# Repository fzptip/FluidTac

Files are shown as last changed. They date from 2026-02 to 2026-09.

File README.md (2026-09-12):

# FluidTac

## A Vision-Based Arrayed Artificial Lateral Line Sensor for Underwater Ego-Motion Estimation

<p align="center">
  
  
  
</p>

**Zhipeng Fei\*, Yicheng Lin\*, Hengpeng Xie, Cong Li, and Bin Han**  

Published in **IEEE Robotics and Automation Letters (RA-L), 2026**.

[[Paper]](https://doi.org/10.1109/LRA.2026.3732929) [[Fabrication Guide]](./FluidTac%20Quick%20Start%20Guide.pdf) [[Code]](./Code) [[Model]](./Model)

## Overview

Reliable ego-motion estimation is essential for autonomous underwater vehicles (AUVs), but conventional sensing methods can degrade in shallow, turbid, and unstructured environments. Doppler velocity logs may lose bottom lock, while vision-based approaches depend on sufficient visibility and image features.

**FluidTac** is a compact, vision-based arrayed artificial lateral line sensor designed to provide robust velocity observations without relying on acoustic bottom tracking or external visual features. Inspired by the lateral line system of fish, FluidTac uses an array of passive propellers to convert local water-flow disturbances into visually observable rotations. A built-in camera tracks the rotational motion of the propellers, and the resulting signals are combined with inertial measurements for underwater ego-motion estimation.

## Method

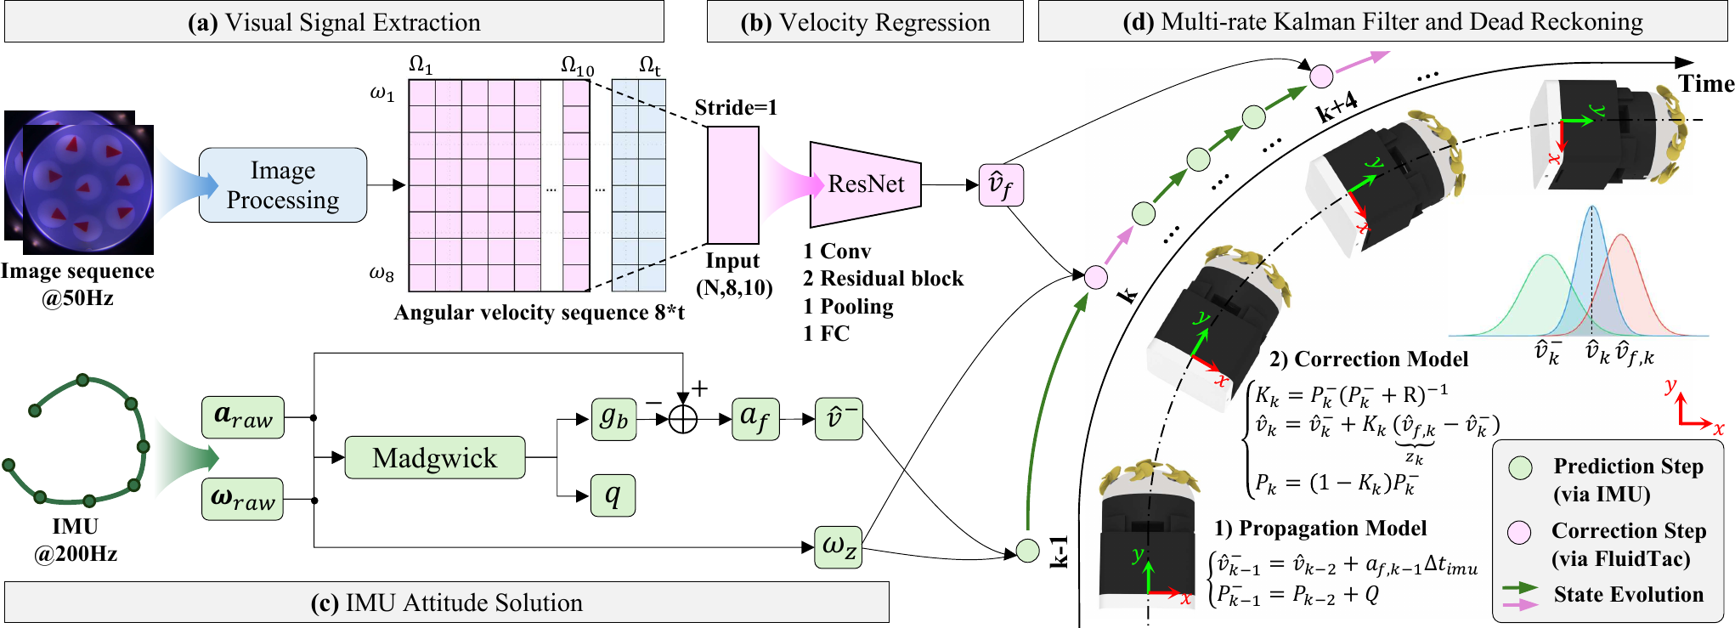
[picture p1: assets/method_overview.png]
Overview of the FluidTac ego-motion estimation framework


The proposed framework consists of four main stages:

1. **Visual signal extraction.** A camera captures the passive propeller array at 50 Hz. Image processing and marker tracking recover the angular velocity of each propeller.
2. **Velocity regression.** A sliding window containing the angular velocities of the eight sensing units is processed by a lightweight 1D ResNet to estimate the vehicle's forward velocity.
3. **IMU attitude estimation.** Raw 200 Hz accelerometer and gyroscope measurements are processed using a Madgwick filter to estimate attitude and gravity-compensated forward acceleration.
4. **Multi-rate sensor fusion.** A Kalman filter propagates the state using high-frequency inertial measurements and corrects the velocity whenever a new FluidTac observation becomes available. The fused velocity and yaw rate are then used for planar dead reckoning.

## Sensor Design

FluidTac employs eight passive propeller units arranged in an omnidirectional circular array. Water flow drives the propellers, while red asymmetric markers rigidly connected to their shafts provide visually trackable angular information. A single wide-angle camera observes all sensing units simultaneously, and an annular LED array provides stable internal illumination.

| Parameter | Value |
| --- | ---: |
| Sensor dimensions | 50 × 50 × 75 mm |
| Total mass | 76.17 g |
| Number of propeller units | 8 |
| Sensing diameter | 25 mm |
| Sampling rate | 50 Hz |
| Velocity range | 0.05-0.50 m/s |
| Front flow-angle range | ±90° |
| Velocity relative error | 3.49% |
| Flow-direction error | 1.71° |
| Signal-to-noise ratio | 5.35-10.04 dB |

## Experiments

FluidTac was evaluated through controlled experiments and real-world field trials:

- **Flow-direction sensing:** the sensor was rotated from -90° to 90° in a controlled current.
- **Velocity sensing:** towing experiments evaluated velocity estimation from 0.1 m/s to 0.5 m/s.
- **Ego-motion estimation:** rectangular and circular trajectories were tested in a motion-capture-equipped water tank.
- **Field validation:** FluidTac was integrated into an AUV and tested in a shallow, highly turbid natural lake.

In the controlled ego-motion experiments, FluidTac achieved the following performance:

| Metric | Result |
| --- | ---: |
| Velocity MAE | 7.99 mm/s |
| Velocity relative error | 3.49% |
| Position MAE | 5.48 cm |
| Position RMSE | 6.57 cm |
| Relative position error | 6.85% of traveled distance |

The lake experiments further demonstrated that FluidTac can constrain inertial drift and maintain reliable trajectory estimation in visually degraded, acoustically constrained environments.

## Repository Contents

```text
FluidTac/
├── Code/                         # Source code
├── Model/                        # FluidTac mechanical model
├── FluidTac Quick Start Guide.pdf
└── README.md
```

- [`Code/`](./Code): source code associated with FluidTac.
- [`Model/`](./Model): mechanical model files for the sensor.
- [`FluidTac Quick Start Guide.pdf`](./FluidTac%20Quick%20Start%20Guide.pdf): fabrication and assembly guide.

## Citation

If you find FluidTac useful in your research, please cite our paper:

```bibtex
@article{fei2026fluidtac,
  author  = {Zhipeng Fei and Yicheng Lin and Hengpeng Xie and Cong Li and Bin Han},
  title   = {{FluidTac}: A Vision-Based Arrayed Artificial Lateral Line Sensor for Underwater Ego-Motion Estimation},
  journal = {IEEE Robotics and Automation Letters},
  year    = {2026},
  pages   = {1--8},
  doi     = {10.1109/LRA.2026.3732929}
}
```

## Acknowledgments

This work was supported in part by the Jing-Jin-Ji Regional Integrated Environmental Improvement National Science and Technology Major Project under Grant 2025ZD1206400, the National Natural Science Foundation of China under Grant 52375015, and the Interdisciplinary Research Program (Robotics and Artificial Intelligence) of Huazhong University of Science and Technology under Grant 2024JCYJ037.

## Contact

For questions about FluidTac, please open an issue in this repository or contact the corresponding author, **Bin Han** ([binhan@hust.edu.cn](mailto:binhan@hust.edu.cn)).

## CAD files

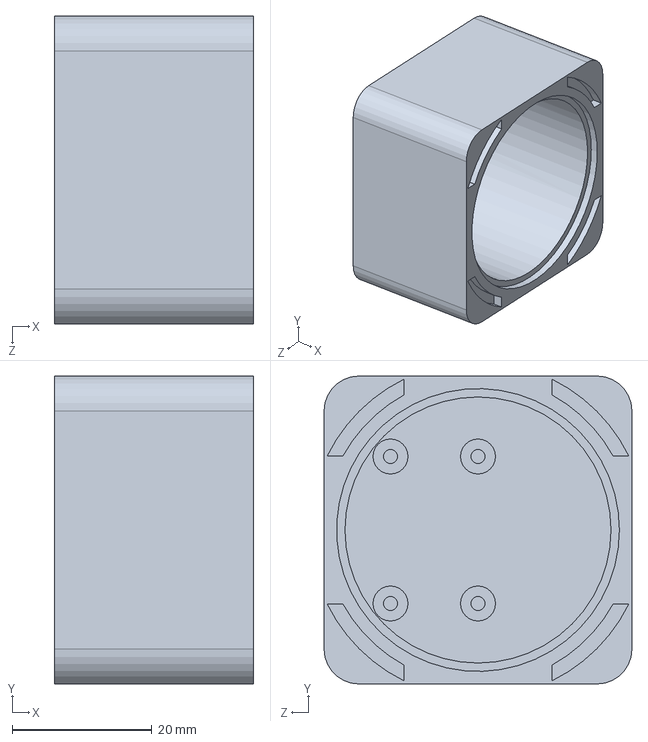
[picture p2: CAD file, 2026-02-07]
Model/Main_body.SLDPRT
28.5 x 44.0 x 44.0 mm

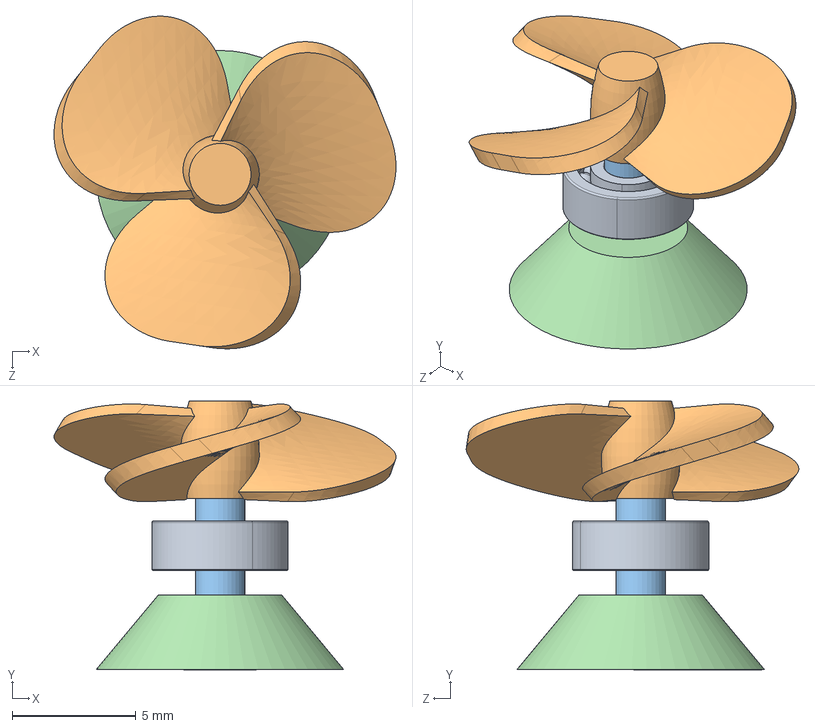
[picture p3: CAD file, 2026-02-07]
Model/Propeller/popular_unit.SLDASM
13.8 x 10.8 x 13.4 mm
Label
Shafts
Propeller_V2
bearings

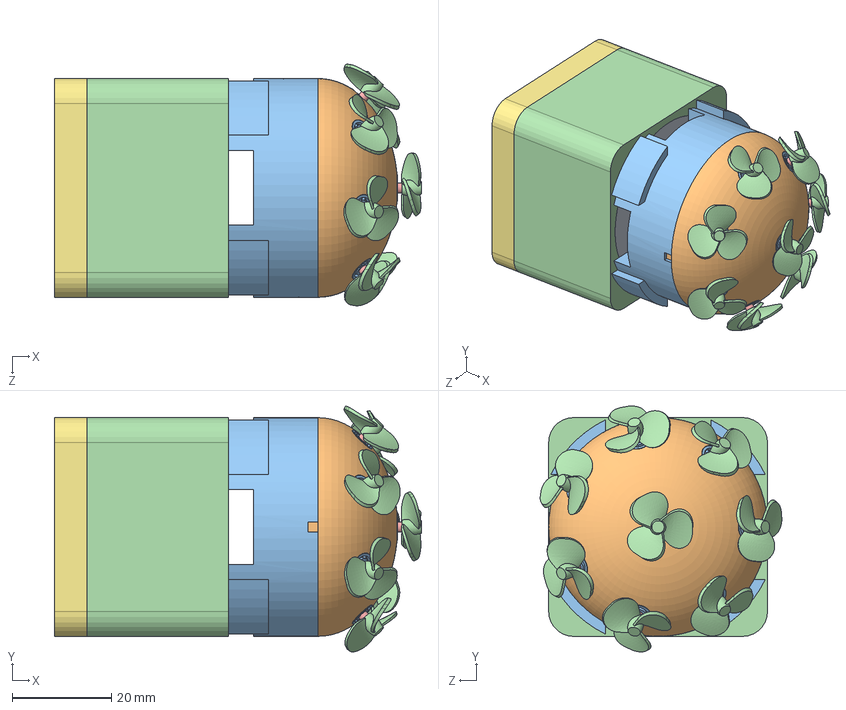
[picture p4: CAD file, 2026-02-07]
Model/FluidTac.SLDASM
73.8 x 49.4 x 48.6 mm
Main_body
LED_base
Bionic_lateral_line
Acrylic_lens
Diffuser
Base
Label x 8
Shafts x 8
Propeller_V2 x 8
bearings x 8
Raspberry Camera
WT901

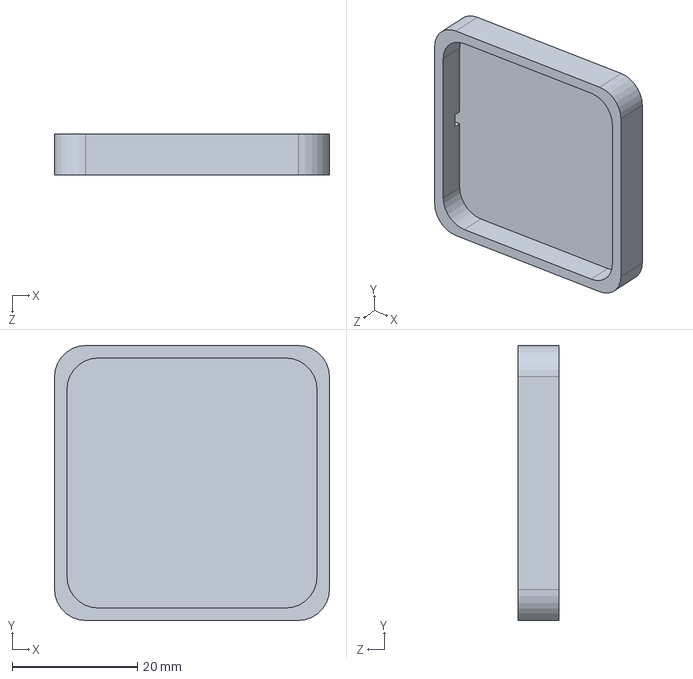
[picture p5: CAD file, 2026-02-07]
Model/Base.SLDPRT
44.0 x 44.0 x 6.50 mm

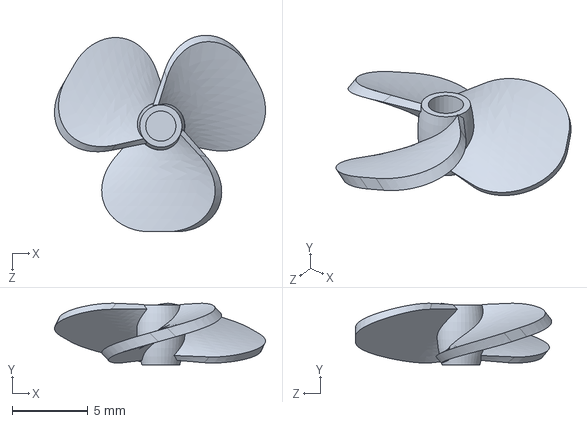
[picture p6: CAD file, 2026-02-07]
Model/Propeller/Propeller_V2.SLDPRT
13.9 x 4.06 x 12.9 mm

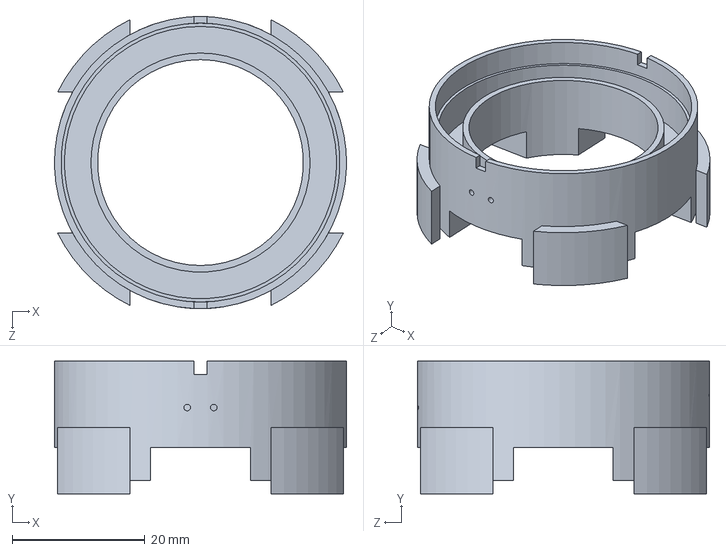
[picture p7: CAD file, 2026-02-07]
Model/LED_base.SLDPRT
44.0 x 20.0 x 44.0 mm

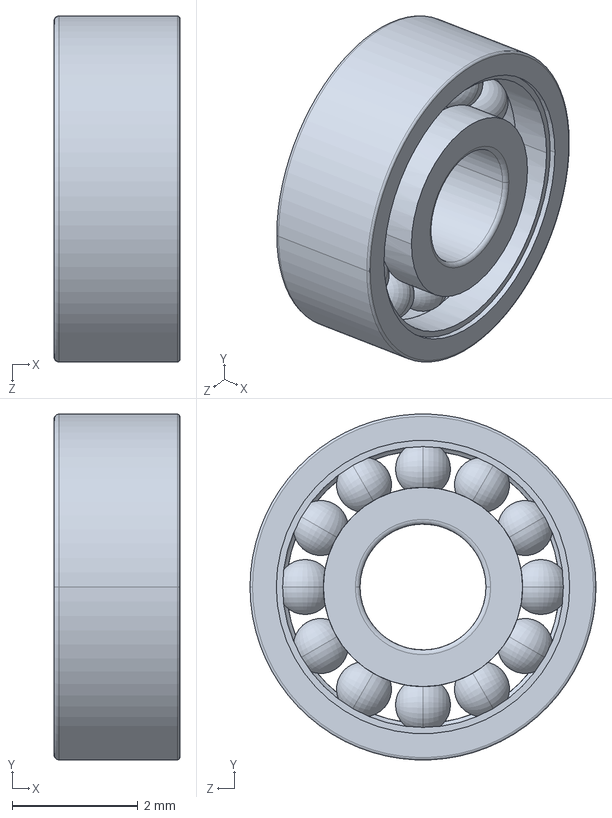
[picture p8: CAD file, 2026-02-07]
Model/Propeller/bearings.SLDPRT
2.00 x 5.50 x 5.50 mm

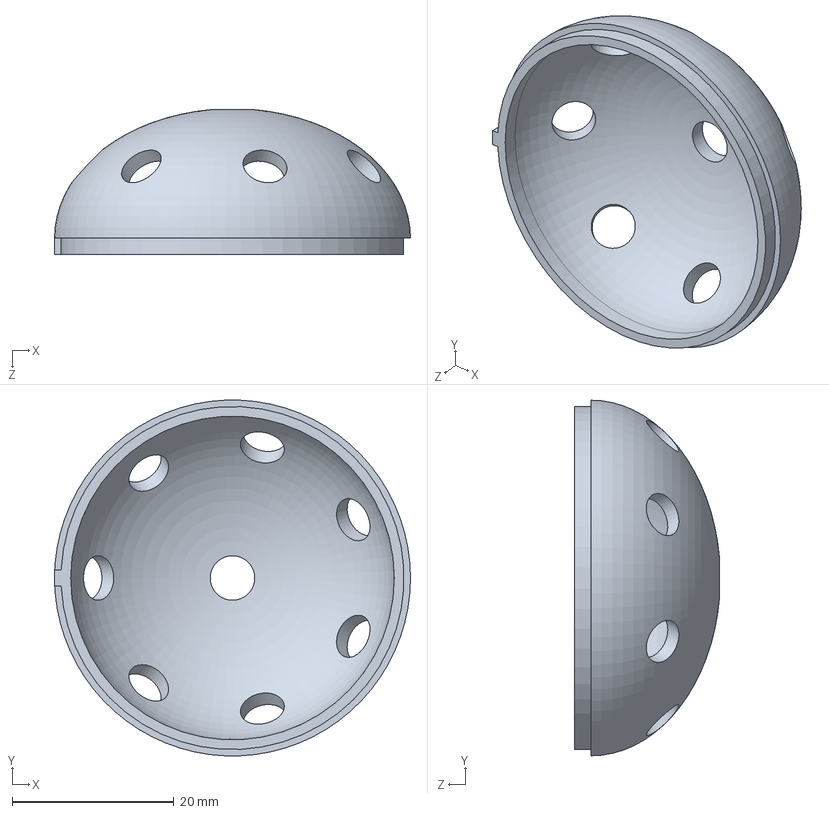
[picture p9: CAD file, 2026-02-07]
Model/Bionic_lateral_line.SLDPRT
44.0 x 44.0 x 17.9 mm

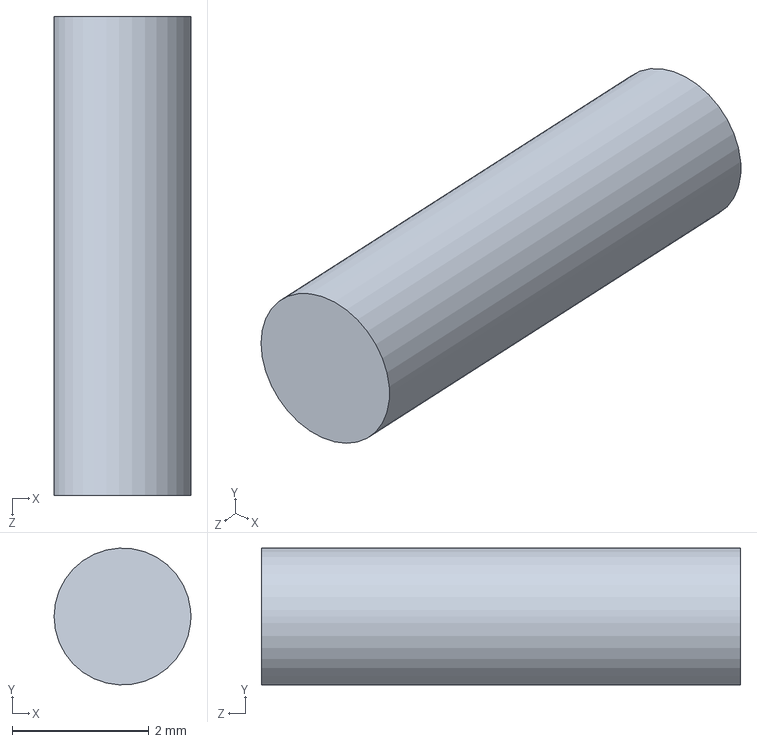
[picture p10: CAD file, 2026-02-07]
Model/Propeller/Shafts.SLDPRT
2.00 x 2.00 x 7.00 mm

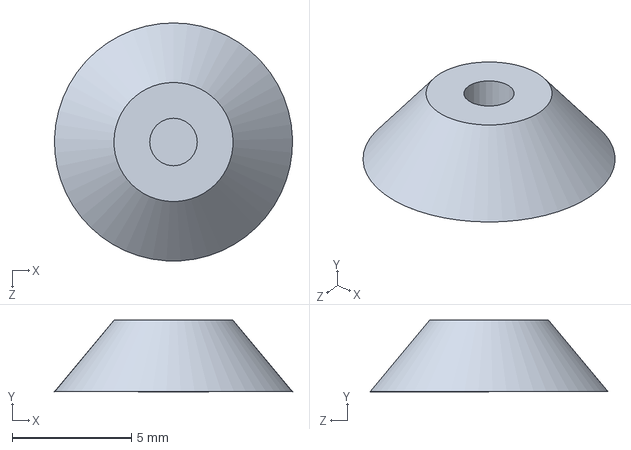
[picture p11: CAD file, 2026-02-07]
Model/Propeller/Label.SLDPRT
10.00 x 3.01 x 10.0 mm

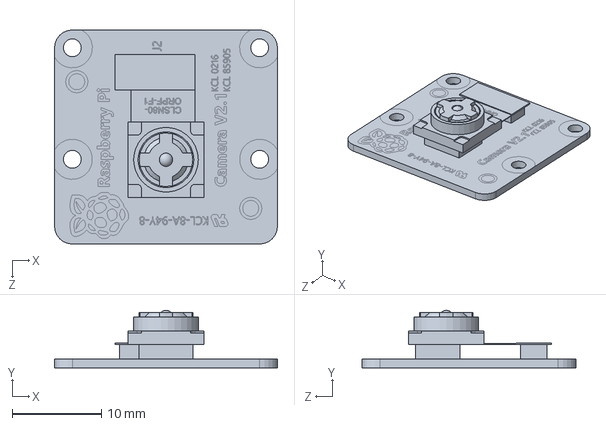
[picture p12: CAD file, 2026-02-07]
Model/Raspberry Camera.SLDPRT
25.0 x 6.45 x 24.0 mm

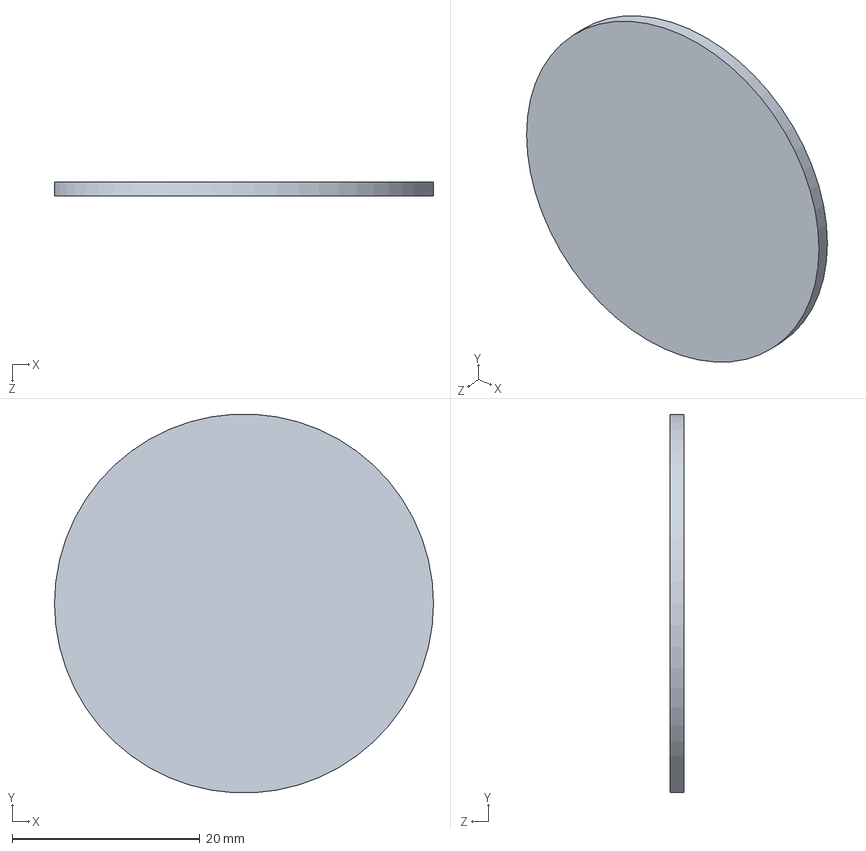
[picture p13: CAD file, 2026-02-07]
Model/Acrylic_lens.SLDPRT
40.4 x 40.3 x 1.50 mm

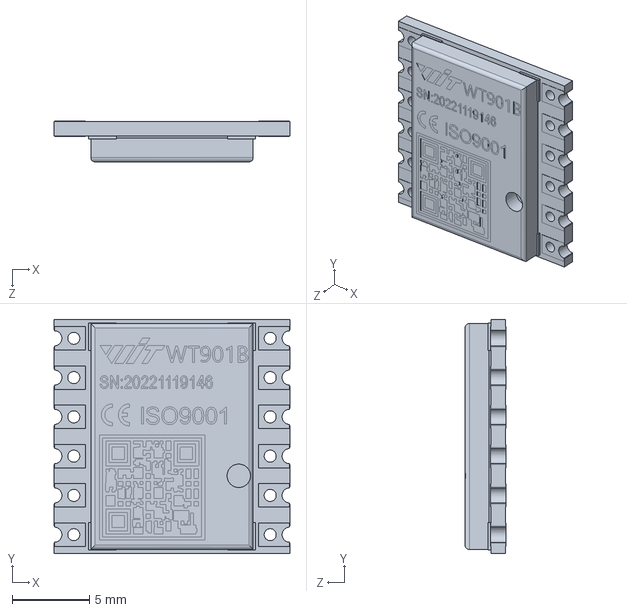
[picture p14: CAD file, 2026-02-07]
Model/WT901.SLDPRT
15.3 x 15.2 x 2.65 mm

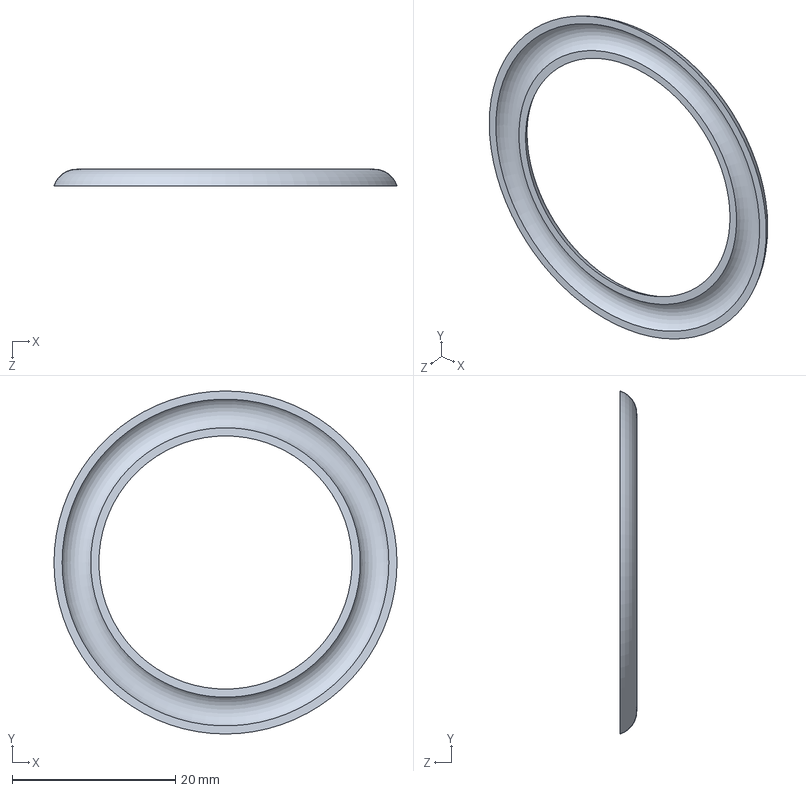
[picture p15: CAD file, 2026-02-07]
Model/Diffuser.SLDPRT
42.0 x 42.0 x 2.02 mm

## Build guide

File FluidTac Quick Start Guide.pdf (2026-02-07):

# FluidTac Quick Start Guide

## 1 Introduction

FluidTac is a high-resolution compact visual-tactile sensor designed to detect water flow velocity and direction in underwater environments. Below is a brief overview of the FluidTac fabrication process.

The required materials are listed in the table below. For certain special items, we've provided purchase links at the end where they can be bought on Taobao.

Component | Specification | Quantity
Casing | Light-curing(JLC Black) | Several
Camera | Raspberry Camera Module 3 | 1
Development board | Raspberry Zero2w | 1
Potting compound | 7018 AB Waterproof sealant | A*1 B*2
Expanded Mirror | 120-degree wide-angle lens[1] | 1
IMU | JY901S
[2] 1
Acrylic sheet | r20 mm | 1
lithium battery | 1000mAh | 1
Fill light | Homemade | 1
Metal Shaft | r1*12mm | 8
Ceramic bearings | 2*5*2.5mm[3] | 8
Passive Propeller | Light-curing(9600) | 8
Waterproof sealant | Black epoxy resin[4] | 2
Label | Light-curing(9600) | 8
Spray painting | Red | 1

All items are arranged on the table as shown in the figure below.

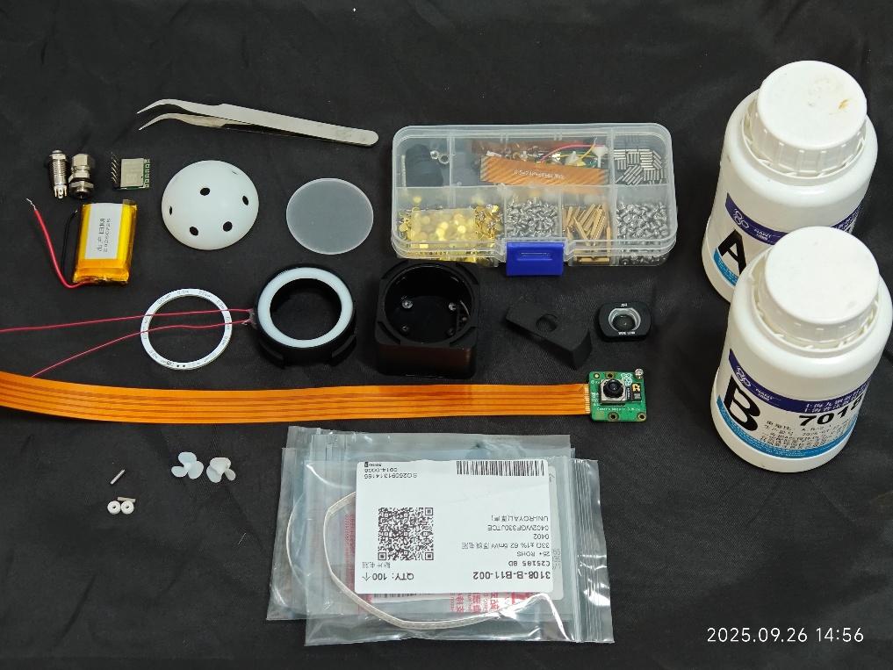
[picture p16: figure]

## 2 Base fabrication

This section describes how to install and construct the camera mount. It does not cover waterproofing design.

The camera base is made using photopolymerization with JLC Black material. The base model file can be found in the attachment. Four screw holes are pre-drilled at the base's bottom for securing the camera to the base. The assembly tutorial is provided below.

1) Connect the camera to the ribbon cable. The base has a pre-drilled hole for the ribbon cable to pass through. Thread the ribbon cable through the base and secure the camera to the base with screws.
2) Due to differing temperature and humidity levels between the above-water and underwater environments, condensation will form on the lens when it is sealed and submerged. Therefore, we need to place a desiccant inside the base. Place the desiccant into the designated compartment within the base, then secure the lid and seal it with super glue.
3) Next, attach the field extender to its corresponding field extender mount and insert the entire assembly into the base.
4) Finally, attach the acrylic sheet to the base and seal it with epoxy resin waterproof adhesive.

The base after completing this step is shown in the figure below.

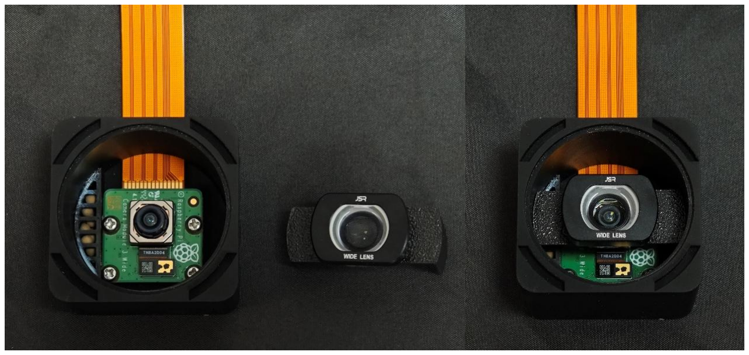
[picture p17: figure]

## 3 Lighting Kit Production

The lighting kit is designed to provide illumination for cameras in dark underwater environments. Since placing the light source inside the base would cause reflections, we need to position it externally. This requires us to make it waterproof.

The circuit board for the fill light module is designed in-house to better accommodate our sensor dimensions and required illumination levels.

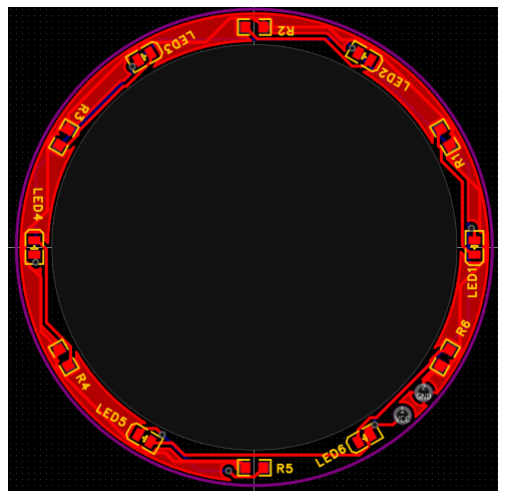
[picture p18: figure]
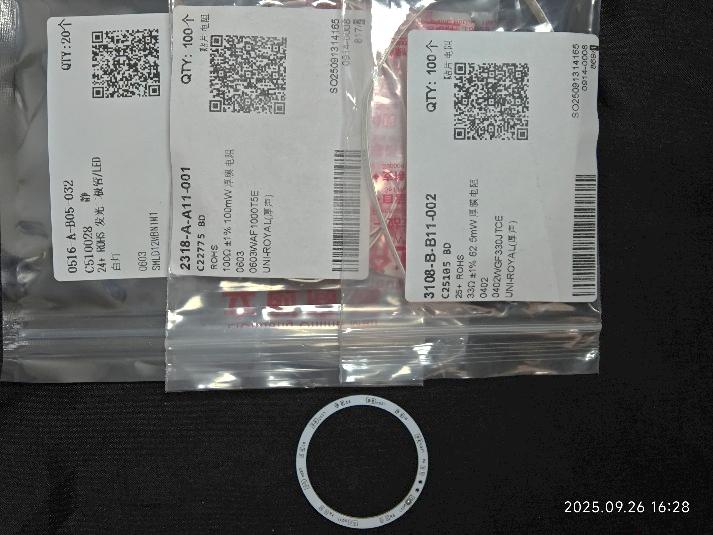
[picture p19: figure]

We designed a ring array of six parallel LED lights and applied copper plating. The surface-mount technology (SMT) process uses 0603 components. Since the lithium battery's rated voltage of 3.7V exceeds the operating voltage of our LEDs, we designed a series of resistors to resolve this. The electronic components used are listed in the table below:

Component | Specification | Quantity
LED | 0603 White | 6
Resistor | 0603 50Ω | 6

The installation distribution tutorial is as follows:

1) Solder the chip resistors and chip LEDs onto the PCB using low-temperature solder paste, then connect two wires to them.
2) Place the finished light ring inside the photopolymerized printed housing made from JLC Black material. Note that the wires must be routed through the housing. Since potting compound will be applied next, seal the wire exit points with a hot glue gun to prevent leakage.
3) Use an electronic scale to weigh out a specific amount of potting compound, then mix them together in a 2:1 ratio until thoroughly blended. Leave undisturbed for 24 hours to allow the potting compound to fully cure.
4) We designed a light-cured printed shell to cover the light ring, serving to homogenize the light source. The shell material is 9600, with a creamy white color.

After assembly, connect the wires to the lithium battery and switch, then attach the lighting module to the base.

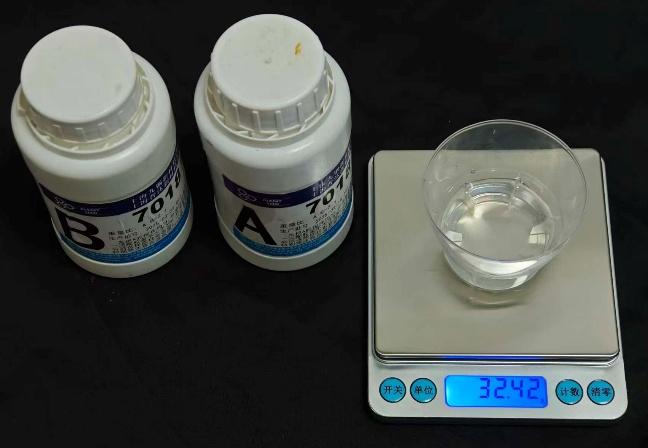
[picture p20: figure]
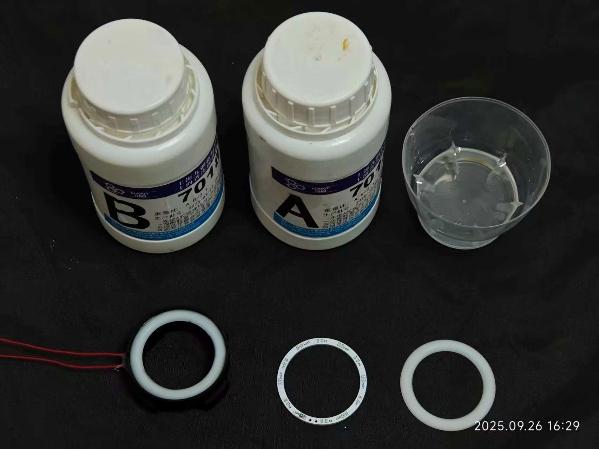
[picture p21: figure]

## 4 Fabrication of Passive Propeller Array

The passive propeller array consists of a series of units. Each unit comprises a passive propeller, a ceramic bearing, a metal shaft, and a label. These units are assembled onto a housing. Both the label and the casing are made from photopolymer materials, specifically 9600.

Passive propellers require sensing minute water currents, so we designed a propeller structure with a large water-facing surface area and low hydraulic resistance. Simultaneously, we employed ceramic bearings to minimize the unit's starting torque and counteract potential underwater corrosion.

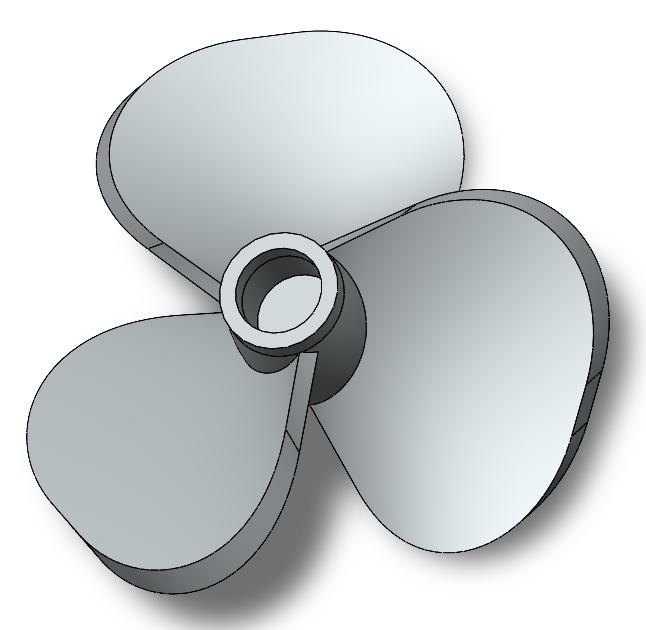
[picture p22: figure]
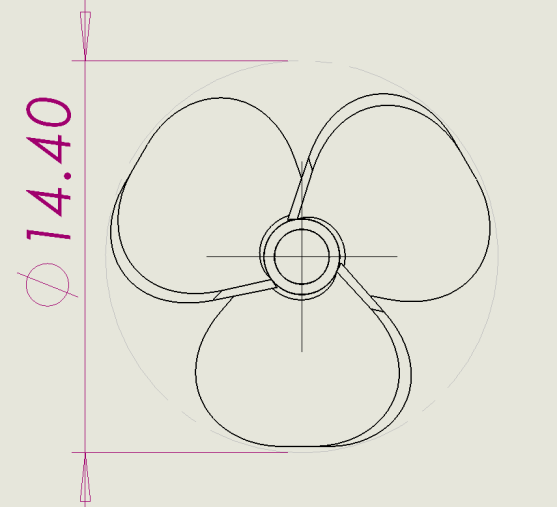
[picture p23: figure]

The materials required for constructing a passive propeller array are shown in the figure below. We will introduce the specific production process.

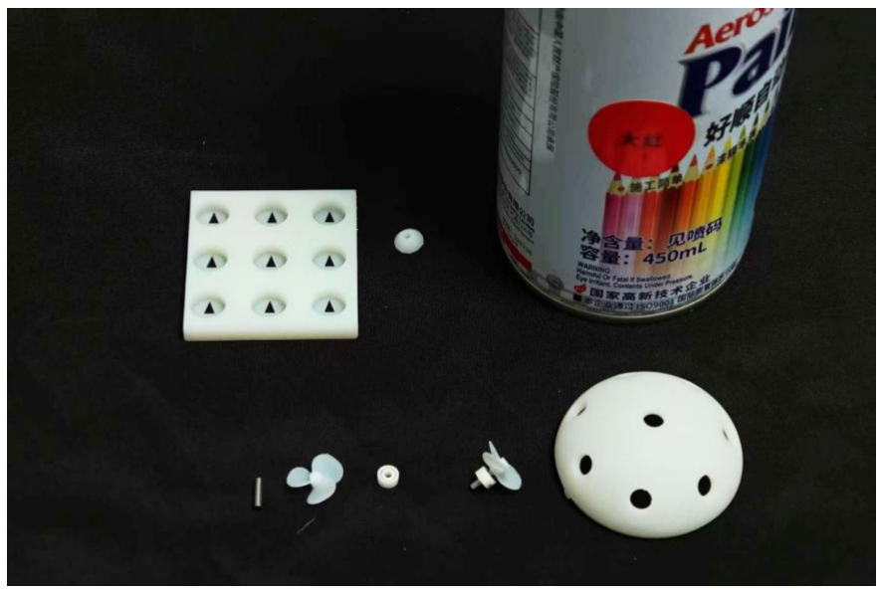
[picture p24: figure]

1) Assemble the passive propeller, metal shaft, and ceramic bearings in sequence. Due to the interference fit, no additional adhesive is required to secure them.
2) Next, install the assembled unit into the housing and test whether its rotational performance is consistent. The housing and bearing also feature an interference fit, eliminating the need for additional adhesive. If no issues are found, proceed to create the label.
3) The printed labels are conical in shape. We designed a mold for producing these labels based on their dimensions, as shown in the figure above. Each label placement area features a triangular hole. Labels can be inserted into the mold, with the exposed triangular sections representing the areas requiring spray painting.
4) Next, we invert the mold and apply bright red spray paint. After spraying, allow it to rest for a period of time before removing the label. This yields a label featuring a triangular emblem on the reverse side. Assemble the label onto the metal shaft.

We have now completed the entire sensor assembly. The array's appearance and the sensor's appearance when illuminated are shown in the figure.

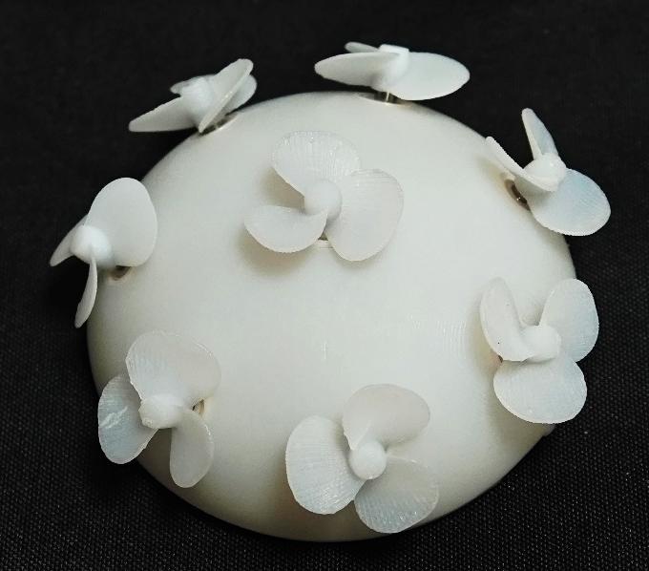
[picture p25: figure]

## Appendix

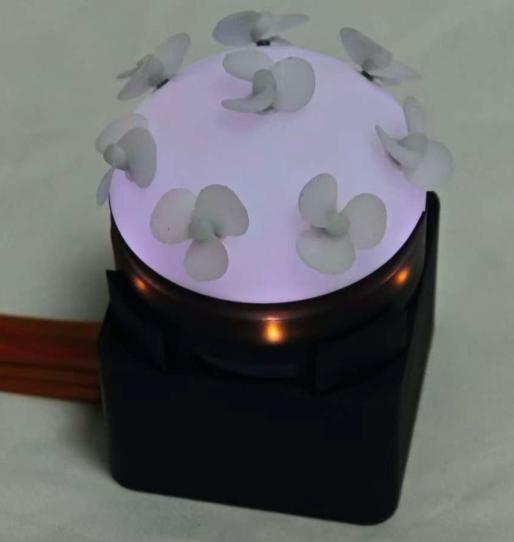
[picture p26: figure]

[1] https://e.tb.cn/h.SkFwh7e242t7kOM?tk=wgdcf3i7HYp HU108
[2] https://e.tb.cn/h.SPbM1dePJWvCAI0?tk=J9Okf3QbfxE CZ057
[3] https://e.tb.cn/h.SPbM1dBIUMlBvsV?tk=eUpQf3QbfC4 HU591
[4] https://e.tb.cn/h.SPHRTvvmuKfHNmp?tk=DCs1f3QbfCP CZ356
